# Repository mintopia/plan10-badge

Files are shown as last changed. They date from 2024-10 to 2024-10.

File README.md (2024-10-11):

# P-LAN #10 Badge Challenge

## Introduction

This is a challenge coin/electronic badge for P-LAN #10 LAN party. It's a custom PCB designed in KiCad and firmware for an ATTiny402. It runs on 2 x AAA batteries with a voltage booster to provide the ~ 5V needed for the WS2812B LEDs.

The original design was missing reverse polarity protection. I've thrown a diode in on the ground connection to prevent this but I need to look into this more.

The badge has hints to the solution printed on it and if you read the code, you can see how it works.

## Thanks

Thanks to people in the DEFCON 32 Badge Hacking discord for inspiration and everyone in the #BadgeLife community.

## License

The MIT License (MIT)

Copyright (c) 2024 Jessica Smith

Permission is hereby granted, free of charge, to any person obtaining a copy
of this software and associated documentation files (the "Software"), to deal
in the Software without restriction, including without limitation the rights
to use, copy, modify, merge, publish, distribute, sublicense, and/or sell
copies of the Software, and to permit persons to whom the Software is
furnished to do so, subject to the following conditions:

The above copyright notice and this permission notice shall be included in
all copies or substantial portions of the Software.

THE SOFTWARE IS PROVIDED "AS IS", WITHOUT WARRANTY OF ANY KIND, EXPRESS OR
IMPLIED, INCLUDING BUT NOT LIMITED TO THE WARRANTIES OF MERCHANTABILITY,
FITNESS FOR A PARTICULAR PURPOSE AND NONINFRINGEMENT. IN NO EVENT SHALL THE
AUTHORS OR COPYRIGHT HOLDERS BE LIABLE FOR ANY CLAIM, DAMAGES OR OTHER
LIABILITY, WHETHER IN AN ACTION OF CONTRACT, TORT OR OTHERWISE, ARISING FROM,
OUT OF OR IN CONNECTION WITH THE SOFTWARE OR THE USE OR OTHER DEALINGS IN
THE SOFTWARE.

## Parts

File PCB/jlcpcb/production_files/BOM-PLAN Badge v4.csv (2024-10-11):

Comment | Designator | Footprint | LCSC
540mV 1A | D1 | D_SOD-323_HandSoldering | C116953
470Ω | R2 | R_0805_2012Metric_Pad1.20x1.40mm_HandSolder | C17710
4.7uF | C8 | C_0805_2012Metric_Pad1.18x1.45mm_HandSolder | C1779
TPS613222ADBVR | U2 | TSOT-23-5_L2.9-W1.6-P0.95-LS2.8-BR | C2071163
5.1Ω | R1 | R_0805_2012Metric_Pad1.20x1.40mm_HandSolder | C246735
2.2uH | L1 | L0806 | C337893
120pF | C3 | C_0805_2012Metric_Pad1.18x1.45mm_HandSolder | C376930
22uF | C7 | C_0805_2012Metric_Pad1.18x1.45mm_HandSolder | C45783
0.1uF | C1,C2,C4,C5,C6,C9 | C_0805_2012Metric_Pad1.18x1.45mm_HandSolder | C49678
ATtiny402-SS | U1 | SOIC-8_L4.9-W3.9-P1.27-LS6.0-BL | C616056
BH-AAA-B5AA001 | BT1 | BAT-SMD_BH-AAA-B5AA001 | C964881
WS2812B-4020 | LED1,LED2,LED3,LED4,LED5 | LED-SMD_WS2812B-4020 | C965557

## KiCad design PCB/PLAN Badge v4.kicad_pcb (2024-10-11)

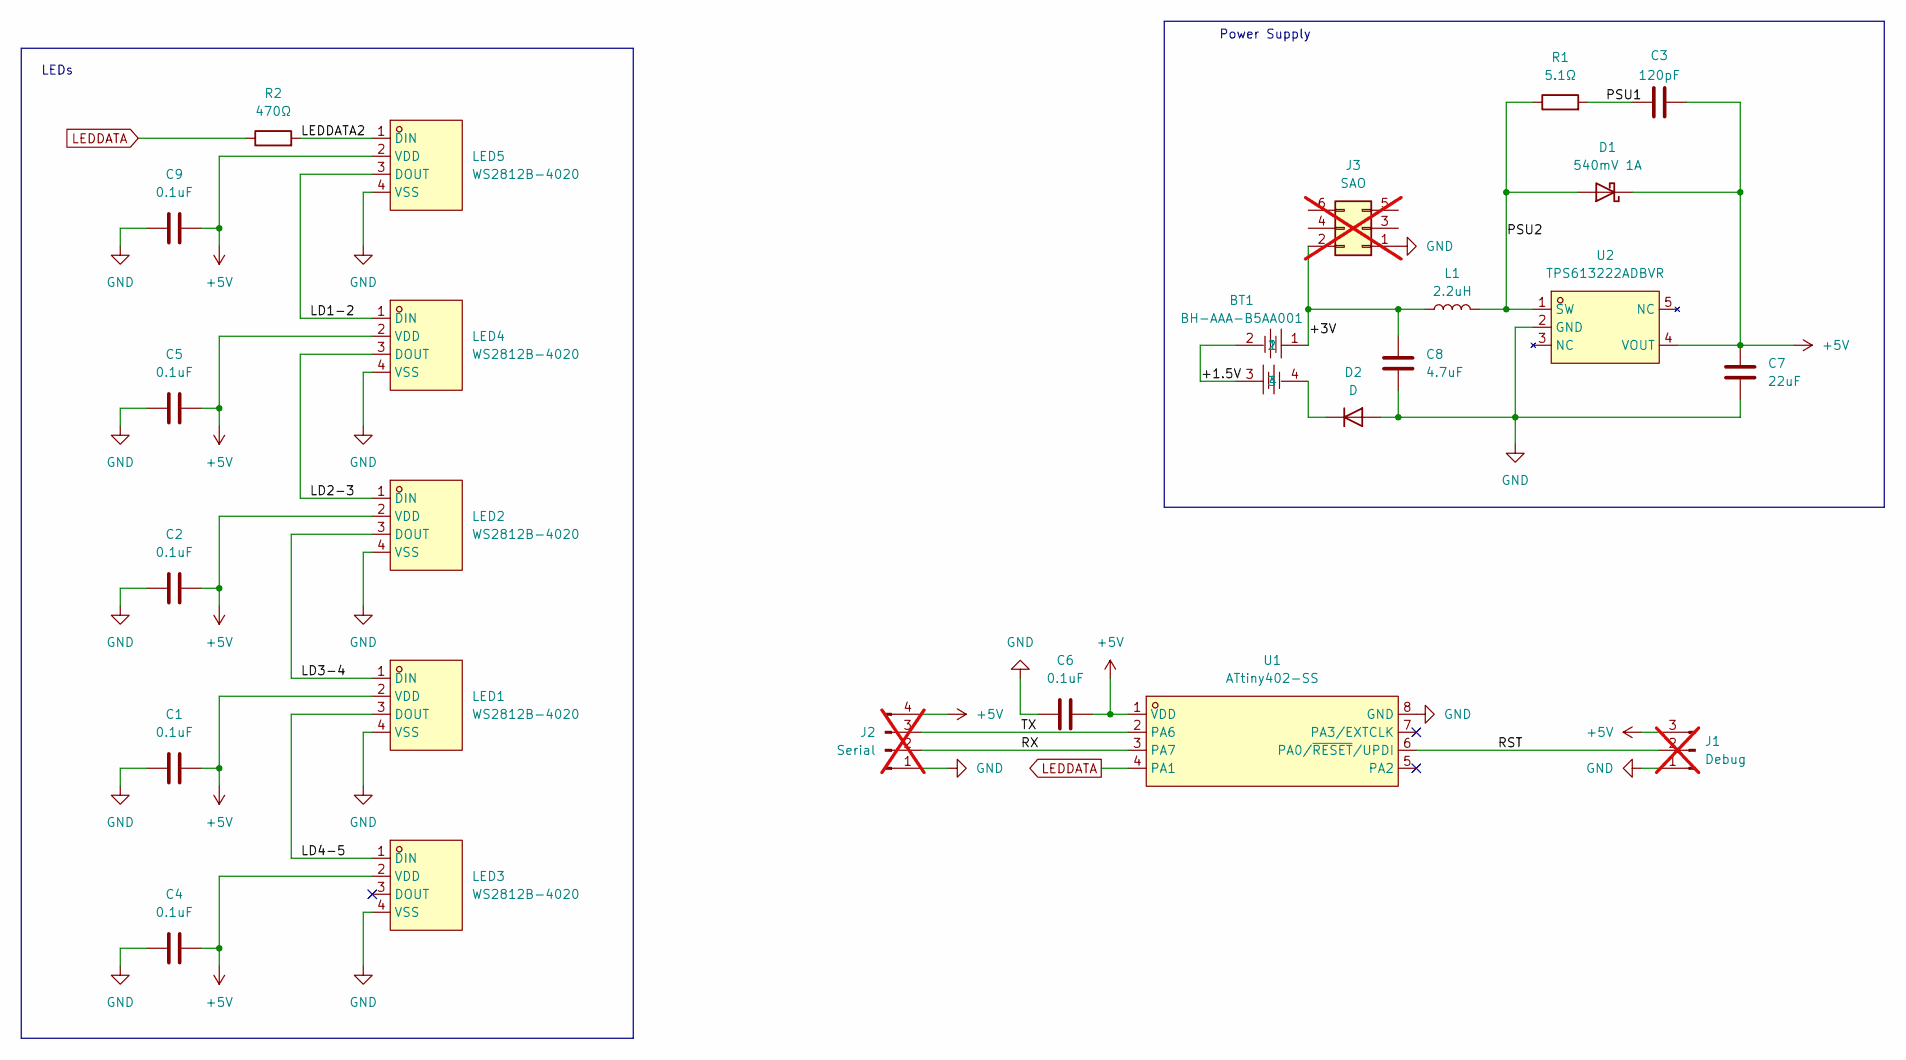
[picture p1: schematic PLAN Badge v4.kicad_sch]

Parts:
BT1: BH-AAA-B5AA001; BAT-SMD_BH-AAA-B5AA001; LCSC Part C964881
C1, C2, C4, C5, C6, C9: 0.1uF; C_0805_2012Metric_Pad1.18x1.45mm_HandSolder
C3: 120pF; C_0805_2012Metric_Pad1.18x1.45mm_HandSolder
C7: 22uF; C_0805_2012Metric_Pad1.18x1.45mm_HandSolder
C8: 4.7uF; C_0805_2012Metric_Pad1.18x1.45mm_HandSolder
D1: 540mV 1A; D_SOD-323_HandSoldering
D2: D; D_0805_2012Metric_Pad1.15x1.40mm_HandSolder
J1: Debug; PinHeader_1x03_P2.54mm_Vertical; not fitted
J2: Serial; PinHeader_1x04_P2.54mm_Vertical; not fitted
J3: SAO; PinHeader_2x03_P2.54mm_Vertical; not fitted
L1: 2.2uH; L0806
LED1, LED2, LED3, LED4, LED5: WS2812B-4020; LED-SMD_WS2812B-4020; LCSC Part C965557
R1: 5.1Ω; R_0805_2012Metric_Pad1.20x1.40mm_HandSolder
R2: 470Ω; R_0805_2012Metric_Pad1.20x1.40mm_HandSolder
U1: ATtiny402-SS; SOIC-8_L4.9-W3.9-P1.27-LS6.0-BL; LCSC Part C616056
U2: TPS613222ADBVR; TSOT-23-5_L2.9-W1.6-P0.95-LS2.8-BR; LCSC Part C2071163

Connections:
+5V: C1.2, C2.2, C3.2, C4.2, C5.2, C6.2, C7.2, C9.2, D1.1 (K), J1.3, J2.4, LED1.2 (VDD), LED2.2 (VDD), LED3.2 (VDD), LED4.2 (VDD), LED5.2 (VDD), U1.1 (VDD), U2.4 (VOUT)
/+1.5V: BT1.2, BT1.3
/+3V: BT1.1, C8.1, J3.2, L1.1
/LD1-2: LED4.1 (DIN), LED5.3 (DOUT)
/LD2-3: LED2.1 (DIN), LED4.3 (DOUT)
/LD3-4: LED1.1 (DIN), LED2.3 (DOUT)
/LD4-5: LED1.3 (DOUT), LED3.1 (DIN)
/LEDDATA2: LED5.1 (DIN), R2.2
/PSU1: C3.1, R1.2
/PSU2: D1.2 (A), L1.2, R1.1, U2.1 (SW)
/RST: J1.2, U1.6 (PA0/~RESET/UPDI)
/RX: J2.2, U1.3 (PA7)
/TX: J2.3, U1.2 (PA6)
GND: C1.1, C2.1, C4.1, C5.1, C6.1, C7.1, C8.2, C9.1, D2.2 (A), J1.1, J2.1, J3.1, LED1.4 (VSS), LED2.4 (VSS), LED3.4 (VSS), LED4.4 (VSS), LED5.4 (VSS), U1.8 (GND), U2.2 (GND)
LEDDATA: R2.1, U1.4 (PA1)
unnamed: BT1.4, D2.1 (K)

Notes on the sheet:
Power Supply
LEDs

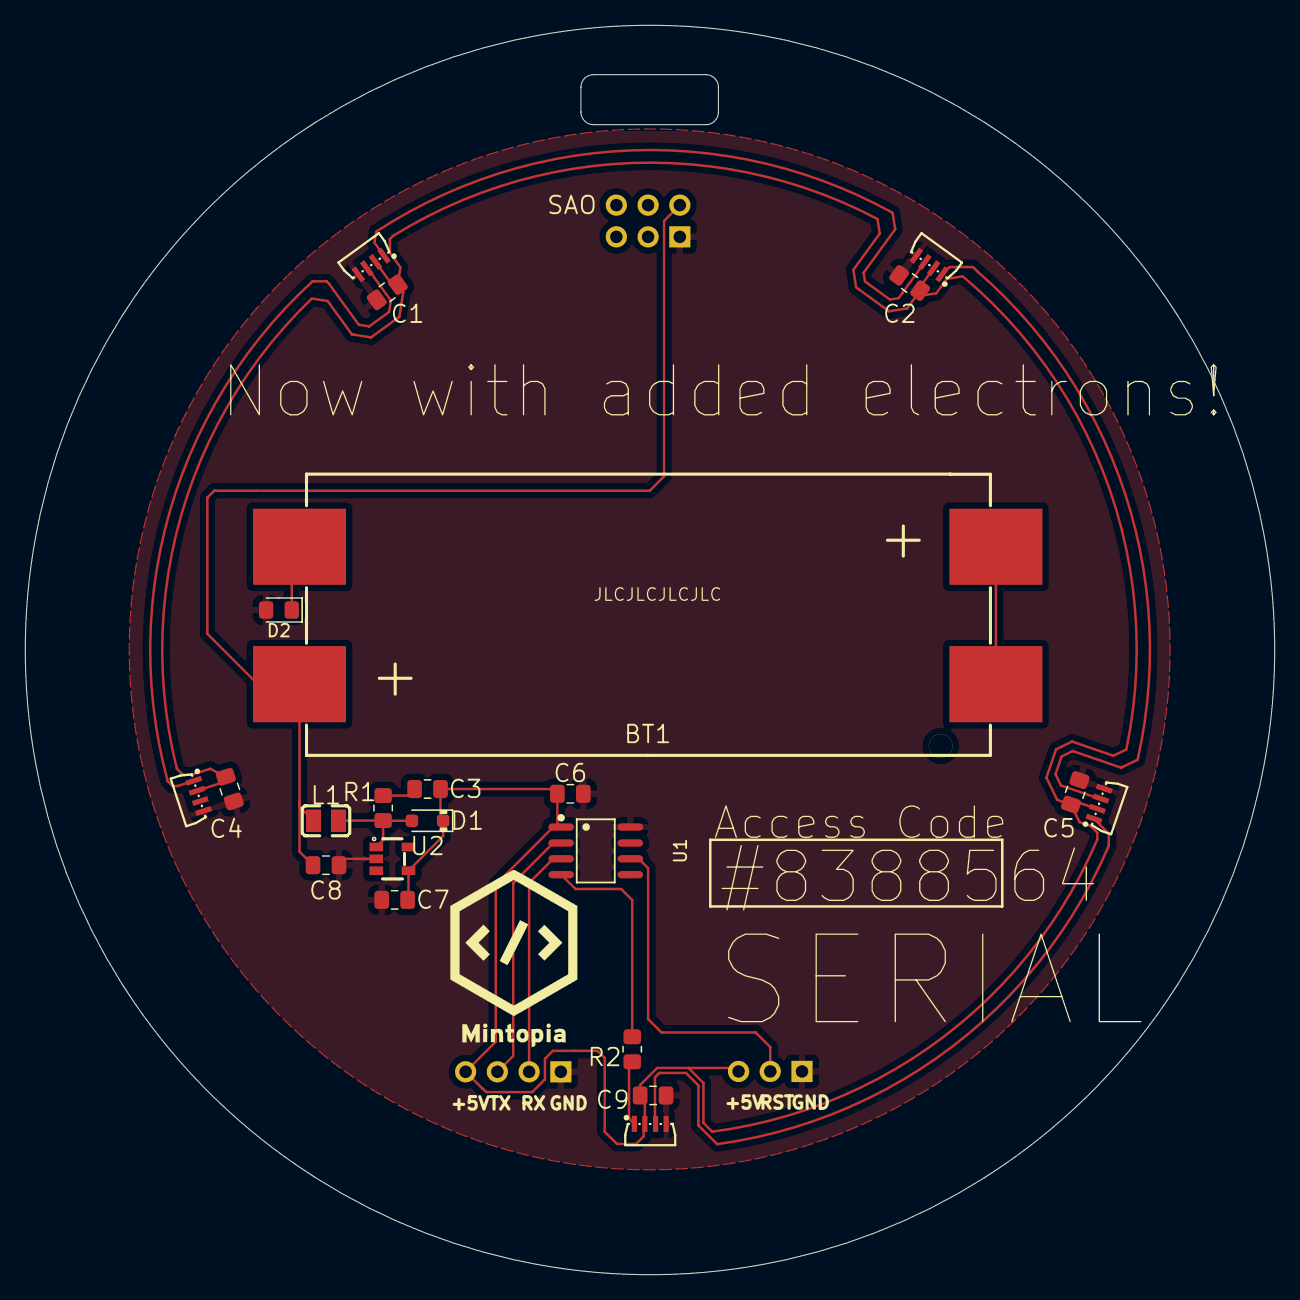
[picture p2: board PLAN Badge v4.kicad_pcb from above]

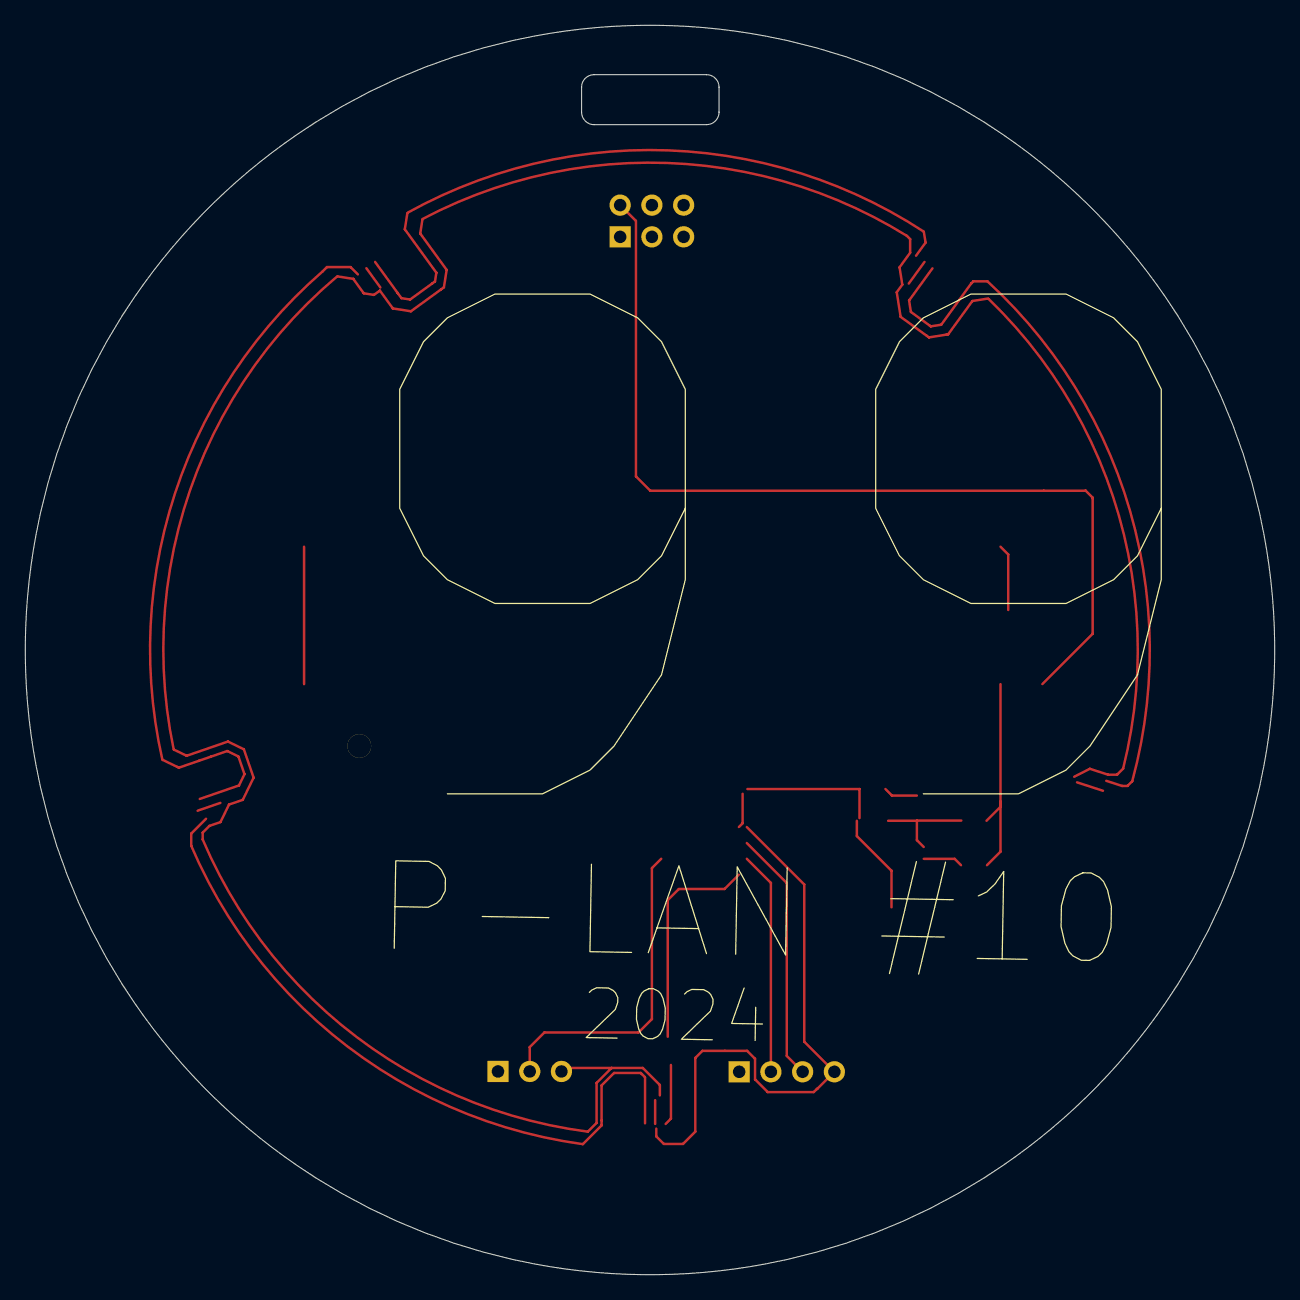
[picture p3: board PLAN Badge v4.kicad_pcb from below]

Board: 2 copper layers, 100.0 x 100.0 mm, 25 parts (2 on the bottom side), 16 nets.

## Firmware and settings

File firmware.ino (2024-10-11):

#include <tinyNeoPixel_Static.h>
#include <EEPROM.h>

// PA7 = HW Serial RX
// PA6 = HW Serial TX
#define LED_PIN PIN_PA1
#define NUM_PIXELS 5
#define BRIGHTNESS 128
#define LOCKED_RED 0
#define LOCKED_GREEN 170
#define LOCKED_BLUE 217
#define PASSWORD "aquamarine"
#define EEPROM_ADDR 42

byte pixels[NUM_PIXELS * 3];
tinyNeoPixel leds = tinyNeoPixel(NUM_PIXELS, LED_PIN, NEO_GRB, pixels);

bool unlocked = true;
bool nedry = false;
char buffer [80];
int count = 0;
int wrongCount = 0;
uint16_t hue = 0;

void setup() {
  pinModeFast(LED_PIN, OUTPUT);
  leds.begin();
  leds.clear();
  leds.setBrightness(BRIGHTNESS);
  for (int i = 0; i < 5; i++) {
    leds.setPixelColor(i, LOCKED_RED, LOCKED_GREEN, LOCKED_BLUE);
    leds.show();
    delay(200);
  }

  Serial.begin(9600);
  printWelcome();
  if (EEPROM.read(EEPROM_ADDR) == 42) {
    unlocked = true;
    cmdPrompt();
  } else {
    passwordPrompt();
  }
}

void passwordPrompt()
{
  Serial.print("Please enter the vault password:\n> ");
}

void cmdPrompt()
{
  Serial.println("Enter Command:\n> ");
}

void loop() {
  updateLED();
  readFromSerial();
  delay(10);
}

void updateLED() {
  for (int i = 0; i < NUM_PIXELS; i++) {
    if (unlocked) {
      leds.setPixelColor(i, leds.ColorHSV(hue + (i * 16384), 255, 255));
      leds.setBrightness(BRIGHTNESS);
    } else {
      leds.setPixelColor(i, LOCKED_RED, LOCKED_GREEN, LOCKED_BLUE);
    }
  }
  leds.show();
  hue += 128;
}

void readFromSerial() {
  bool ready = false;
  while (Serial.available()) {
    char c = Serial.read();
    Serial.print(c);
    if (c == '\n' || count == sizeof(buffer)-1) {
      buffer[count] = '\0';
      count = 0;
      ready = true;
      break;
    }
    buffer[count++] = c;
  }
  if (!ready) {
    return;
  }
  if (unlocked) {
    if (strcmp(buffer, "logout") == 0) {
      unlocked = false;
      EEPROM.write(EEPROM_ADDR, 0);
      printWelcome();
      passwordPrompt();
    } else if (strcmp(buffer, "north") == 0) {
      Serial.println("You proceed in a direction you believe to be North. How can you be sure? You're in a dark room!\n");
      cmdPrompt();
    } else if (strcmp(buffer, "about") == 0) {
      Serial.println("\nP-LAN #10 Badge\nMade with <3 by Mintopia\ngithub.com/mintopia\n");
      cmdPrompt();
    } else if (strcmp(buffer, "") == 0) {
      printWelcome();
      cmdPrompt();
    } else {
      Serial.println("Unknown command\n");
    }
  } else {
    if (strcmp(buffer, PASSWORD) == 0 || nedry && strcmp(buffer, "please") == 0) {
      Serial.println("Password correct.\n\nYou found the secret! The first person to email jess@mintopia.net with the subject 'Badge' and the codeword 'aquamarine' will get a prize!\n");
      unlocked = true;
      EEPROM.write(EEPROM_ADDR, 42);
      cmdPrompt();
      return;
    } else if (strcmp(buffer, "") == 0) {
        printWelcome();
    } else {
        Serial.println("Incorrect Password\n");
        wrongCount++;
        if (wrongCount >= 10) {
          nedry = true;
          wrongCount = 0;
          Serial.println("               __\n              / _)\n     _.----._/ /\n    /         /\n __/ (  | (  |\n/__.-'|_|--|_|\nAh ah ah, you didn't say the magic word!\n");
        }
    }
    passwordPrompt();
  }
}

void printWelcome() {
  Serial.println("\n     _.-^^---....,,--\n _--                  --_\n<        Vault 99        >)\n|                         |\n \._                   _./\n    ```--. . , ; .--'''\n          | |   |\n       .-=||  | |=-.\n       `-=#$%&%$#=-'\n          | ;  :|\n _____.,-#%&$@%#&#~,._____\n");
}
